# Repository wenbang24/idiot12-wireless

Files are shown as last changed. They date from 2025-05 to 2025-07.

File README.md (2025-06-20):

# idiot12-wireless
the idiot12, now in wireless form factor (see [https://github.com/wenbang24/idiot17](https://github.com/wenbang24/idiot17) and [https://github.com/wenbang24/idiot12](https://github.com/wenbang24/idiot12) for context)

a wireless split keyboard with every alpha key fitting on one layer with 12 keys
uses holyiot 18010 nRF52840 module, USB-C charging, and Kailh Choc switches

reduce your finger movement, and have your thumb and pinky free to do other things
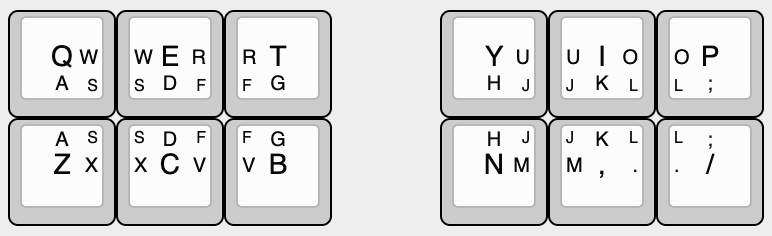
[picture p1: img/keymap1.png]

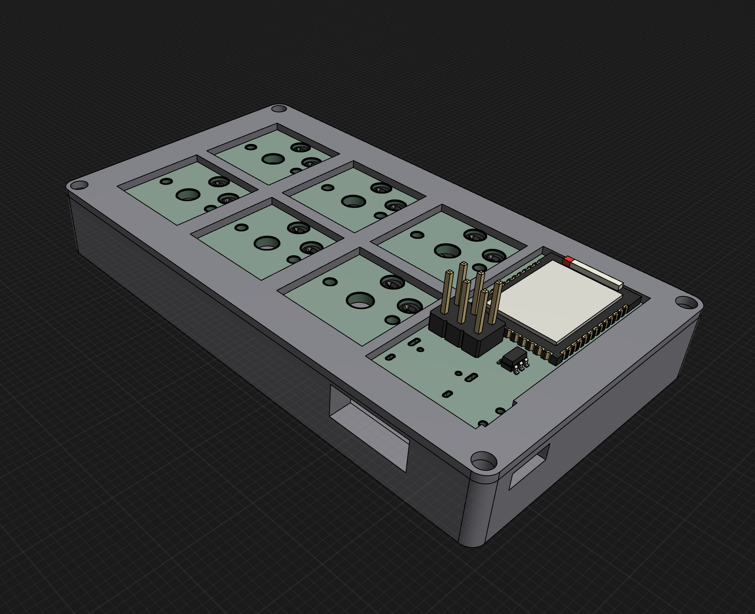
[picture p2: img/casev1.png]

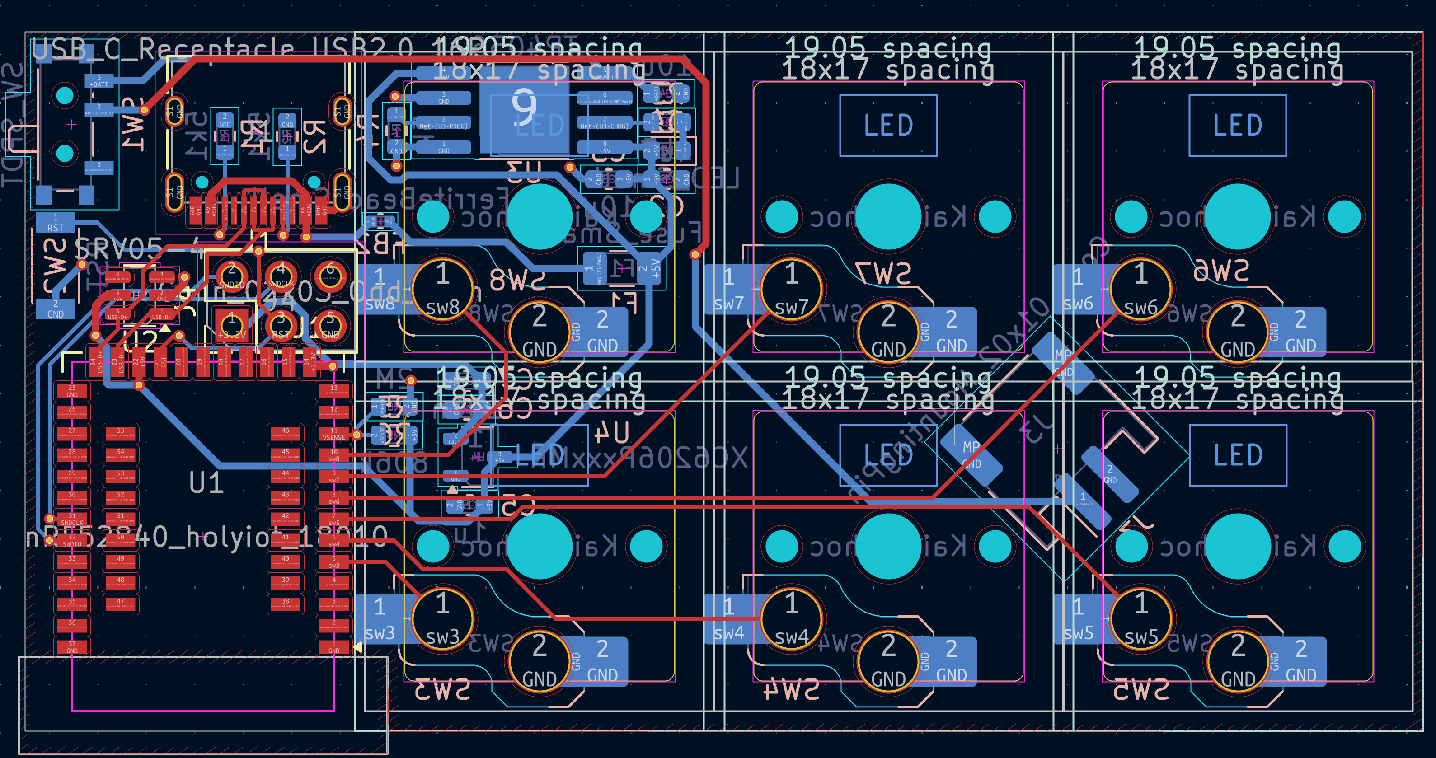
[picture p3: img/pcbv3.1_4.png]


# BOM
This is just for one side; double it for both sides.
|Designator |Footprint |Quantity|Value |LCSC Part #|
|---|---|---|---|---|
|C2 |0603 |1 |4u7 |C19666 |
|C3, C4 |0603 |2 |10u |C19702 |
|C5, C6 |0603 |2 |1u |C15849 |
|C7 |0603 |1 |100n |C14663 |
|D2 |0603 |1 |LED_Small |C2286 |
|F1 |1206 |1 |Fuse_Small |C151162 |
|FB2 |0402 |1 |FerriteBead_Small |C160976 |
|J1 |USB_C_Receptacle_HRO_TYPE-C-31-M-12 |1 |USB_C_Receptacle_USB2.0_16P|C165948 |
|J3 |JST_PH_S2B-PH-SM4-TB_1x02-1MP_P2.00mm_Horizontal|1 |Conn_01x02_MountingPin |C295747 |
|J4 |PinHeader_2x03_P2.54mm_Vertical |1 |Conn_02x03_Odd_Even |C5116479 |
|R1, R2 |0603 |2 |5k1 |C23186 |
|R3 |0603 |1 |1k5 |C22843 |
|R4 |0603 |1 |5k |C23186 |
|R5 |0603 |1 |806k |C403362 |
|R6 |0603 |1 |2M |C4077045 |
|SW1 |SW_SPDT_PCM12 |1 |SW_SPDT |C221841 |
|SW2 |TS-1088R-02526 |1 |RST |C720477 |
|SW3, SW4, SW5, SW6, SW7, SW8|SW_choc_v1_HS_CPG135001S30_1u |6 |Kailh_Choc | |
|U1 |nRF52840_holyiot_18010 |1 |nRF52840_holyiot_18010 | |
|U2 |SOT-23-6 |1 |SRV05-4 |C316033 |
|U3 |SOP-8-1EP_4.57x4.57mm_P1.27mm_EP4.57x4.45mm |1 |TP4056 |C16581 |
|U4 |SOT-23-3 |1 |XC6206PxxxMR |C5446 |

## Parts to source yourself:
- Holyiot 18010 e.g. [this](https://www.aliexpress.com/item/32868002366.html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)
- USB-C receptacle (TYPE-C-31-M-12) e.g. [this](https://www.aliexpress.com/item/1005003285152827.html)
- SRV-05 e.g. [this](https://www.aliexpress.com/item/1005007499115687.html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)
- 2.54mm 2x3 pin header e.g. [this](https://www.aliexpress.com/item/4000303366348.html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)
- 3.7V LiPo battery (around 120mAh) with 2mm JST PH header e.g. [this](https://core-electronics.com.au/lipo-polymer-lithium-ion-battery-120mah.html)
- 4x M3 10mm screws e.g. [this](https://www.bunnings.com.au/pinnacle-m3-x-10mm-zinc-plated-round-head-bolts-and-nuts-20-pack_p0247262)
- 6x Kailh Choc switches e.g. [this](https://www.aliexpress.com/item/1005005883472162.html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)
- 6x Kailh Choc keycaps e.g. [this](https://www.aliexpress.com/item/32949747794.html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)

PCBA cost: $34.56
**Cost**: $84.29 USD (excluding shipping)

Estimated total: $100 USD

(prices converted from AUD to USD, accurate as of 2025-06-16)

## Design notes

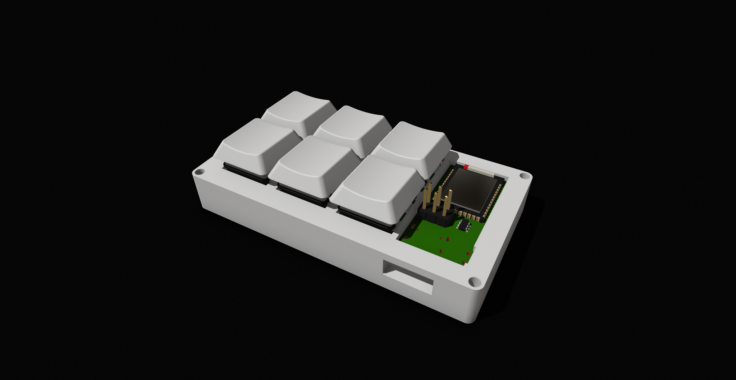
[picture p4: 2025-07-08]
img/Untitled.png

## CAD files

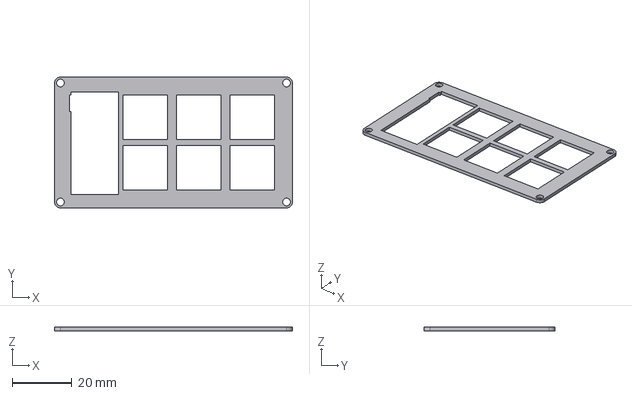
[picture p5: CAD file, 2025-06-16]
case/plate.step
80.0 x 44.0 x 1.20 mm

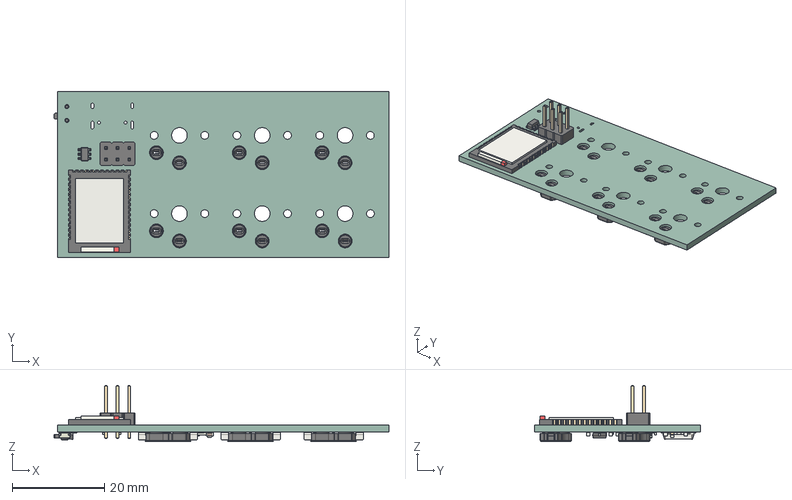
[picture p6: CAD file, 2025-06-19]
pcb/pcb.step
72.8 x 36.1 x 12.2 mm
SOT-23-6
PinHeader_2x03_P2.54mm_Vertical
holyiot_18010_nRF52840
pin x 12
socket x 6
R_0603_1608Metric x 6
Fuse_1206_3216Metric
SW_SPST_B3U-1000P
C_0603_1608Metric x 6
LED_0603_1608Metric
SOT-23-3
SW_SPDT_PCM12
C_0402_1005Metric
pcb_PCB

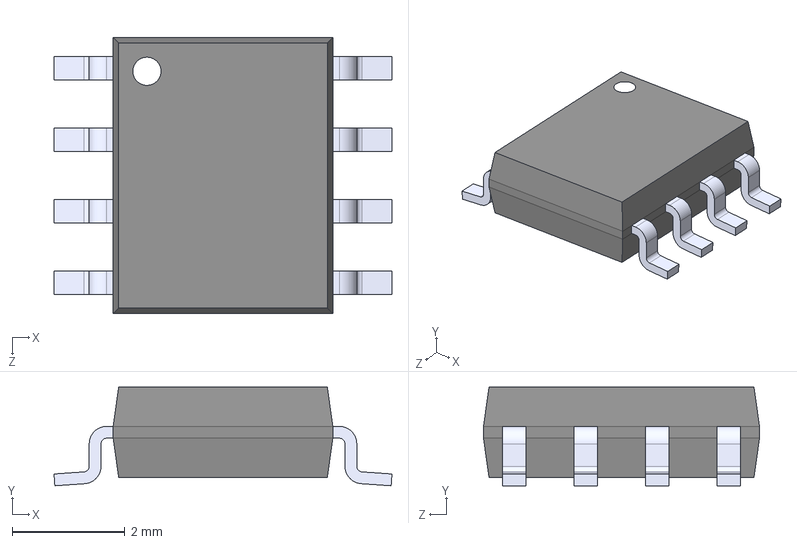
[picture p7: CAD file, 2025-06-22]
pcb/TP4056/TP4056.step
6.00 x 1.75 x 4.90 mm

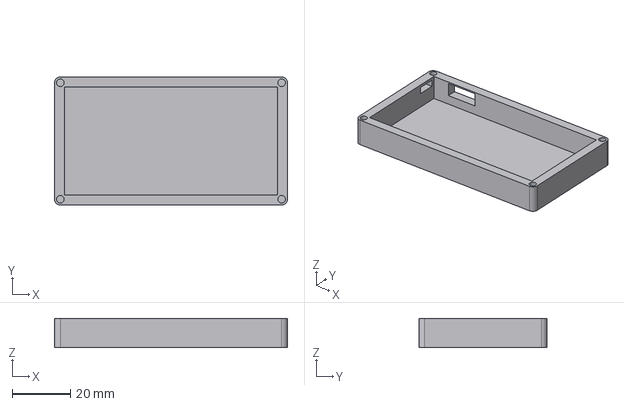
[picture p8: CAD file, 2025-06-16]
case/case.step
80.0 x 44.0 x 10.0 mm

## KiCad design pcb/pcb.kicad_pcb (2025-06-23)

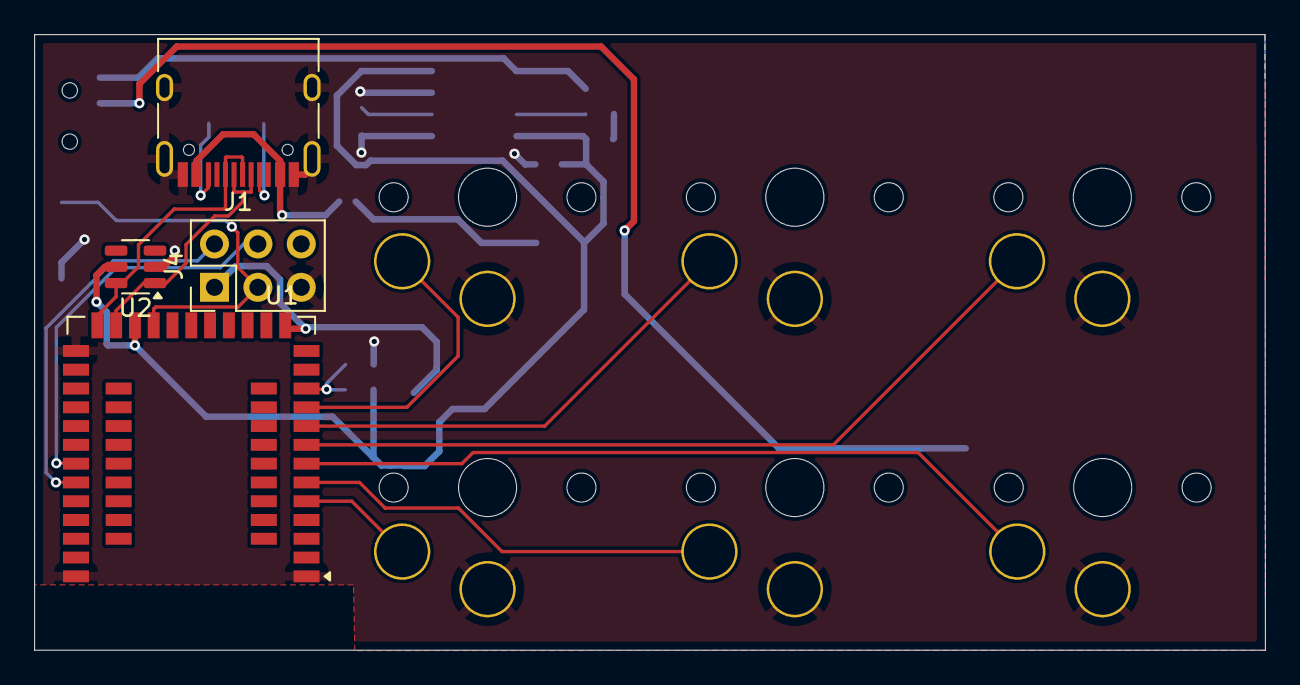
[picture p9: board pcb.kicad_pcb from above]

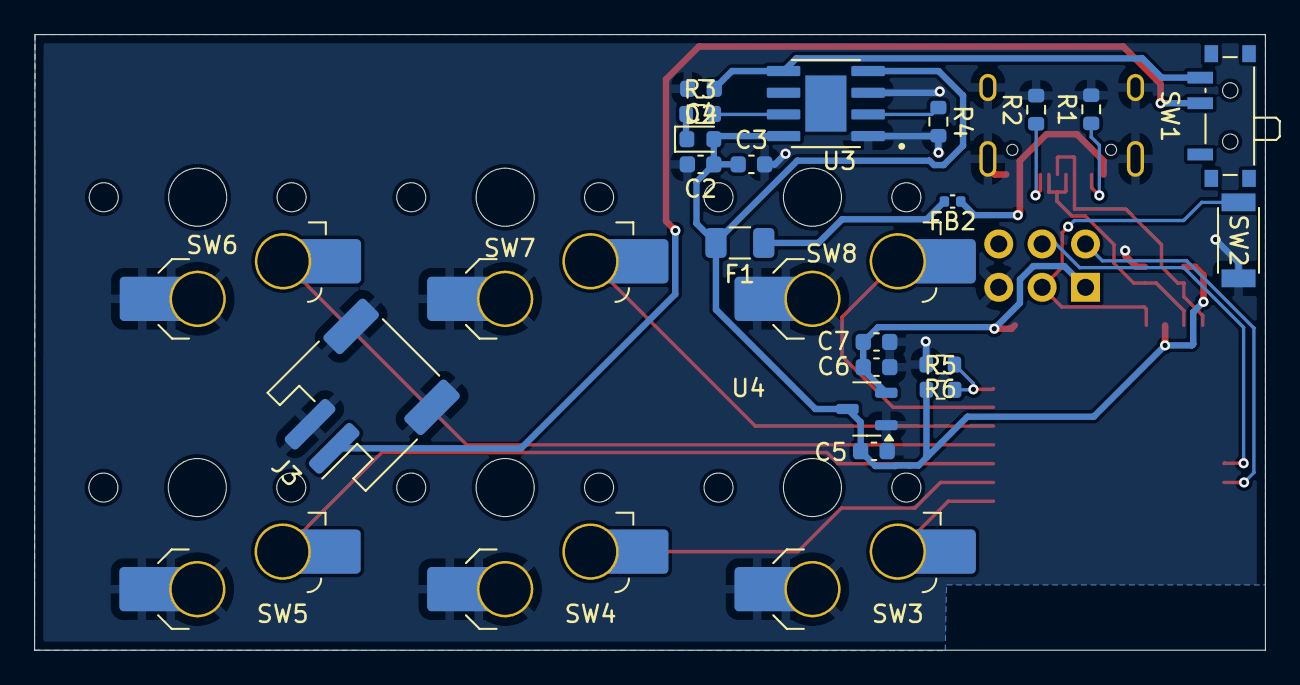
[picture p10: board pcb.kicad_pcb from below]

Board: 2 copper layers, 72.1 x 36.1 mm, 30 parts (26 on the bottom side), 24 nets.

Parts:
C2: 4u7; C_0603_1608Metric
C3, C4: 10u; C_0603_1608Metric
C5, C6: 1u; C_0603_1608Metric
C7: 100n; C_0603_1608Metric
D2: LED_Small; LED_0603_1608Metric
F1: Fuse_Small; Fuse_1206_3216Metric
FB2: FerriteBead_Small; C_0402_1005Metric
J1: USB_C_Receptacle_USB2.0_16P; USB_C_Receptacle_HRO_TYPE-C-31-M-12
J3: Conn_01x02_MountingPin; JST_PH_S2B-PH-SM4-TB_1x02-1MP_P2.00mm_Horizontal
J4: Conn_02x03_Odd_Even; PinHeader_2x03_P2.54mm_Vertical
R1, R2: 5k1; R_0603_1608Metric
R3: 1k5; R_0603_1608Metric
R4: 5k; R_0603_1608Metric
R5: 806k; R_0603_1608Metric
R6: 2M; R_0603_1608Metric
SW1: SW_SPDT; SW_SPDT_PCM12
SW2: RST; TS-1088R-02526
SW3, SW4, SW5, SW6, SW7, SW8: Kailh_Choc; SW_choc_v1_HS_CPG135001S30_1u
U1: nRF52840_holyiot_18010
U2: SRV05-4; SOT-23-6
U3: TP4056; SOP127P600X175-9N
U4: XC6206PxxxMR; SOT-23-3

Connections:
+3.3V: C6.1, C7.1, J4.1, U1.14 (VDD_nRF), U4.2 (VO)
+5V: C2.1, C3.1, C5.1, D2.2 (A), F1.2, R5.1, U1.22 (VBUS), U2.5 (VP), U3.4 (VCC), U3.8 (CE), U4.3 (VI)
+BATT: C4.1, SW1.3 (C), U3.5 (BAT)
/RST: J4.3, SW2.1, U1.21 (P0.18-RESET)
/SWDCLK: J4.4, U1.31 (SWDCLK)
/SWDIO: J4.2, U1.32 (SWDIO)
/USB-D+: J1.A6 (D+), J1.B6 (D+), U1.24 (D+), U2.6 (IO4)
/USB-D-: J1.A7 (D-), J1.B7 (D-), U1.23 (D-), U2.1 (IO1)
/VSENSE: R5.2, R6.1, U1.11 (P0.31-LF-A)
/sw3: SW3.1, U1.5 (P1.15-LF)
/sw4: SW4.1, U1.6 (P0.03-LF-A)
/sw5: SW5.1, U1.7 (P0.02-LF-A)
/sw6: SW6.1, U1.8 (P0.28-LF-A)
/sw7: SW7.1, U1.9 (P0.29-LF-A)
/sw8: SW8.1, U1.10 (P0.30-LF-A)
GND: C2.2, C3.2, C4.2, C5.2, C6.2, C7.2, J1.A1 (GND), J1.A12 (GND), J1.B1 (GND), J1.B12 (GND), J1.S1 (SHIELD), J3.2, J3.MP (MountPin), J4.5, R1.2, R2.2, R4.2, R6.2, SW2.2, SW3.2, SW4.2, SW5.2, SW6.2, SW7.2, SW8.2, U1.1 (GND), U1.25 (GND), U1.37 (GND), U2.2 (VN), U3.1 (TEMP), U3.3 (GND), U4.1 (GND)
unnamed: D2.1 (K), R3.1
unnamed: F1.1, FB2.2
unnamed: J1.A5 (CC1), R2.1
unnamed: J1.B5 (CC2), R1.1
unnamed: J3.1, SW1.2 (B)
unnamed: R3.2, U3.7 (CHRG)
unnamed: R4.1, U3.2 (PROG)
VBUS: FB2.1, J1.A4 (VBUS), J1.A9 (VBUS), J1.B4 (VBUS), J1.B9 (VBUS)

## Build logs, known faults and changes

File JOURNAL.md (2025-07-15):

---
title: "Idiot12 Wireless Edition"
author: "Ben Wang"
description: "12 keys, one alpha layer - now in wireless form factor!"
created_at: "2025-05-22"
---

total time (so far): 32 hrs

# Journal of Changes
## 22 May 2025 - Keymap
Initial draft of the alpha layer (note: will probably not use qwerty because most frequently used letters should only require one keypress)


Explanation:
- Press Q for Q
- Press Q and Z for A
- Press Q, E, Z, and C for S

(a bit of a weird system but its kinda cool)

Time spent: 30 mins

## 24 May 2025 - Schematic
1st draft of the schematic - hoping it doesn't blow up :)

Time spent: 3 hrs
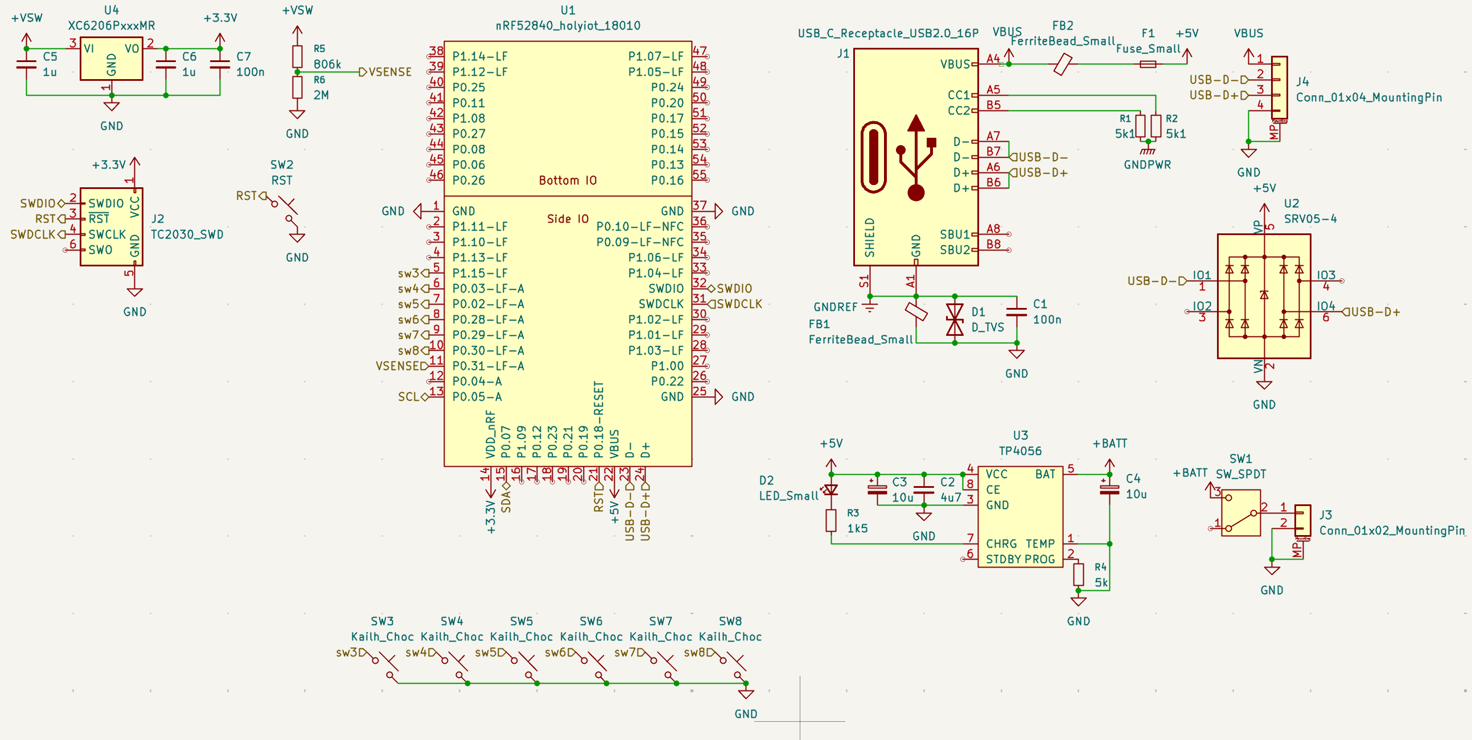
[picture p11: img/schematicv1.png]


2nd draft - removed some unnecessary voltage sensing circuitry

Time spent: 1 hr
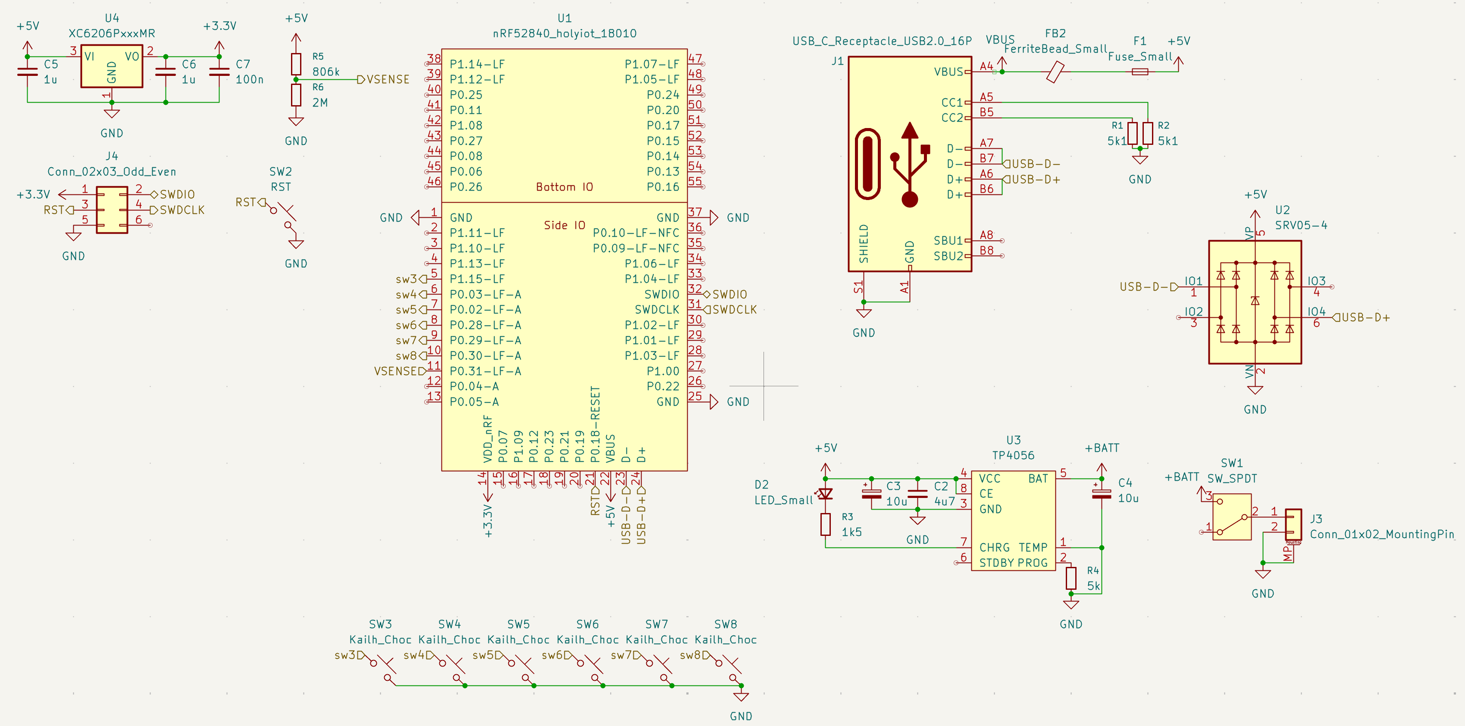
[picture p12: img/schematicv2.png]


## 29 May 2025 - PCB Routing
@koeg on Slack has told me that my schematic is ok :)

Removed the really expensive debug connector and replaced it with a normal 6 pin ICSP header

Also routed the PCB

Time spent: 4.5 hrs
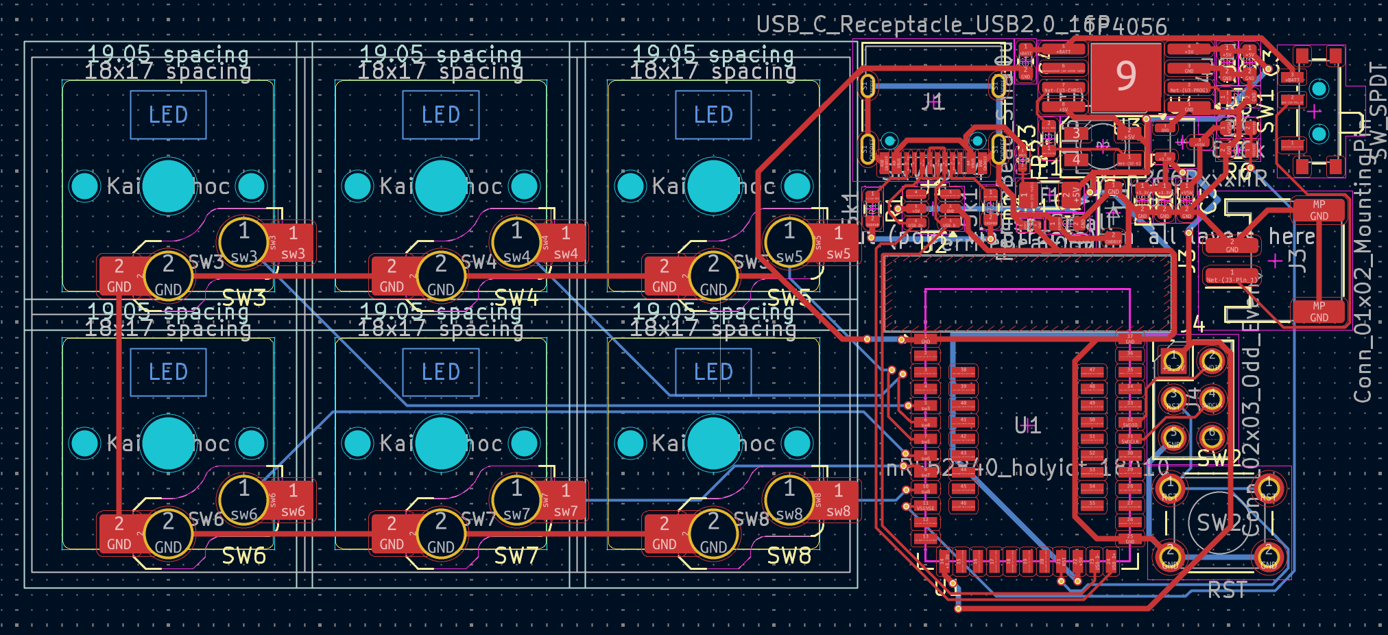
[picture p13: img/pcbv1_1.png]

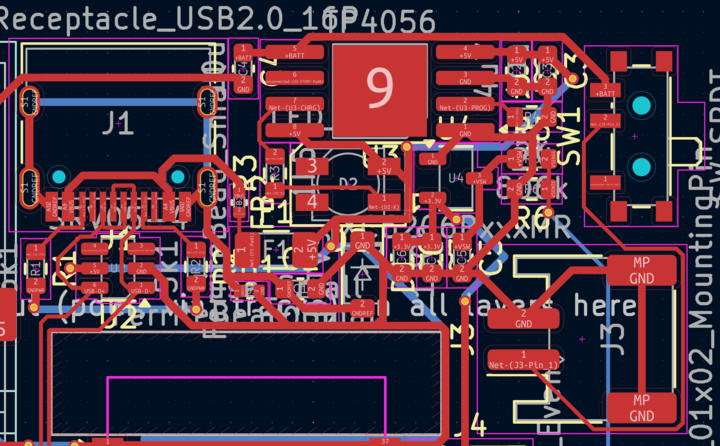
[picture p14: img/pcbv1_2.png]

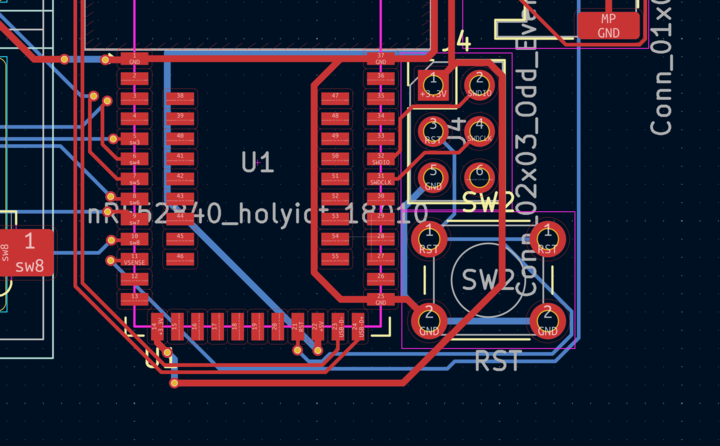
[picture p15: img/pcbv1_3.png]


## 30 May 2025 - PCB Review, starting v2
@koeg has reviewed my PCB (tysm), added a ground and 5V plane, so restarted routing

Time spent: 3 hrs

## 31 May 2025 - PCB Review, v2
A new day, a new PCB iteration

Finished 2nd draft of PCB, awaiting review

Time spent: 3 hrs
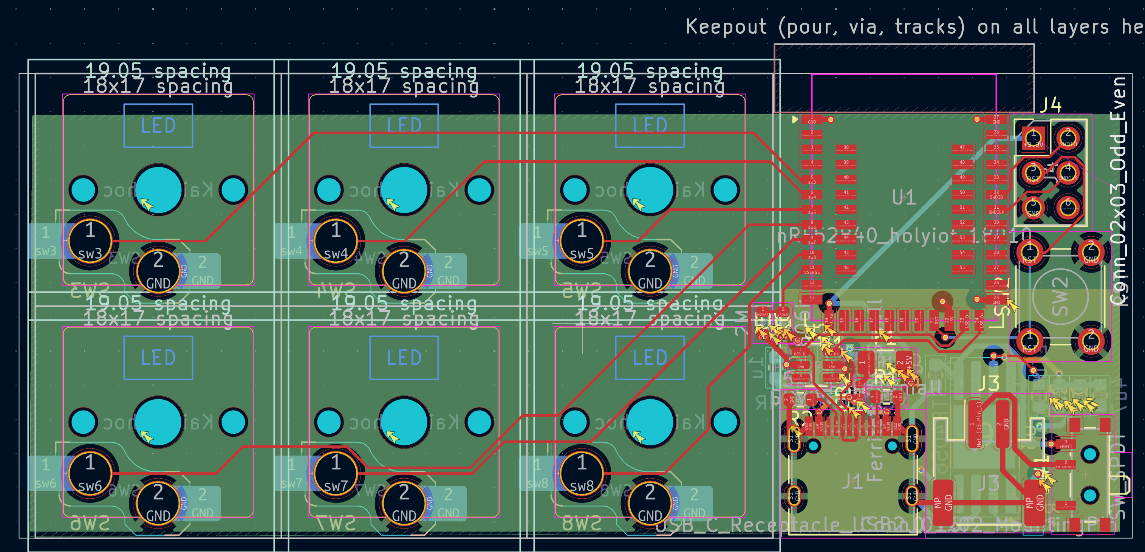
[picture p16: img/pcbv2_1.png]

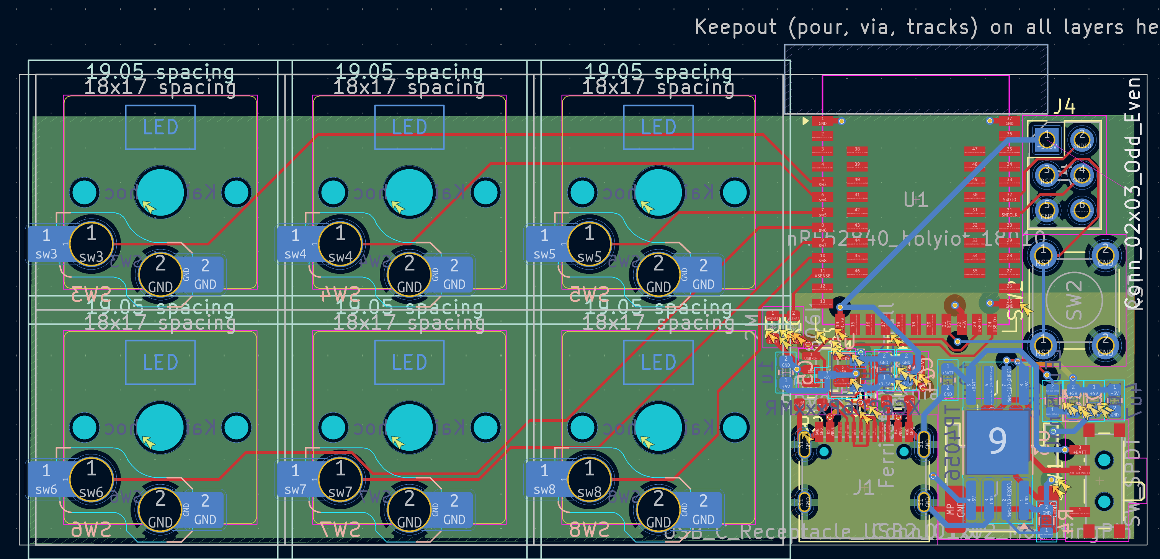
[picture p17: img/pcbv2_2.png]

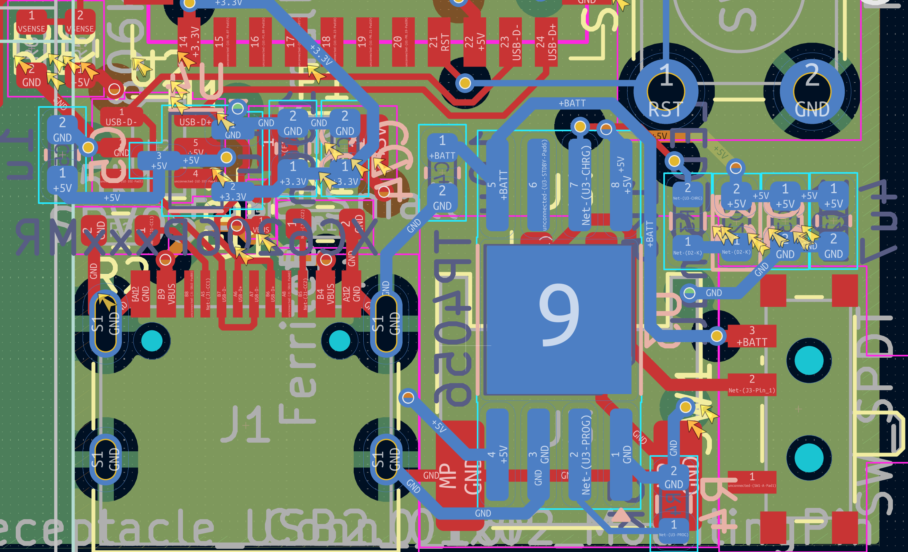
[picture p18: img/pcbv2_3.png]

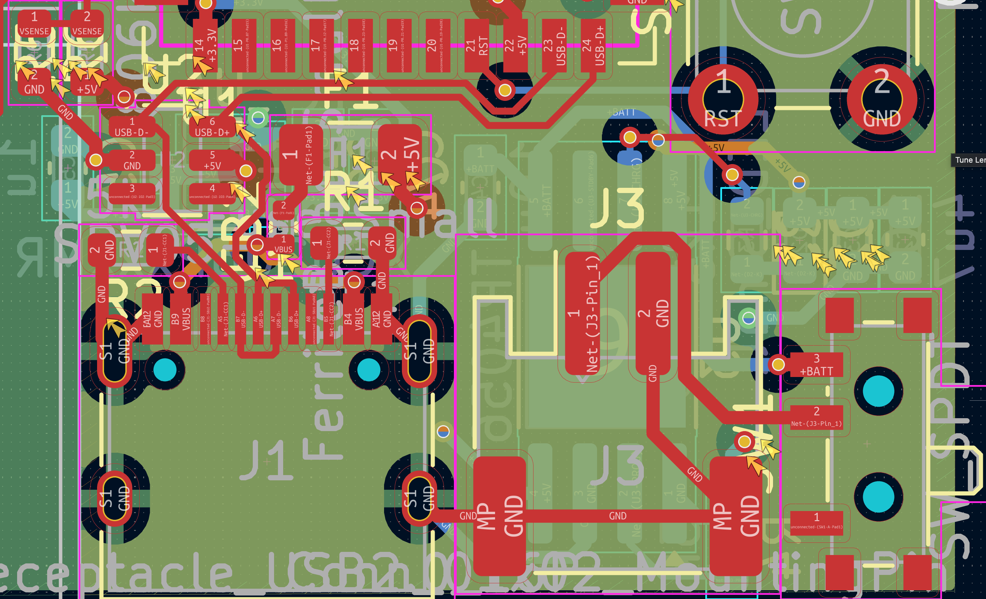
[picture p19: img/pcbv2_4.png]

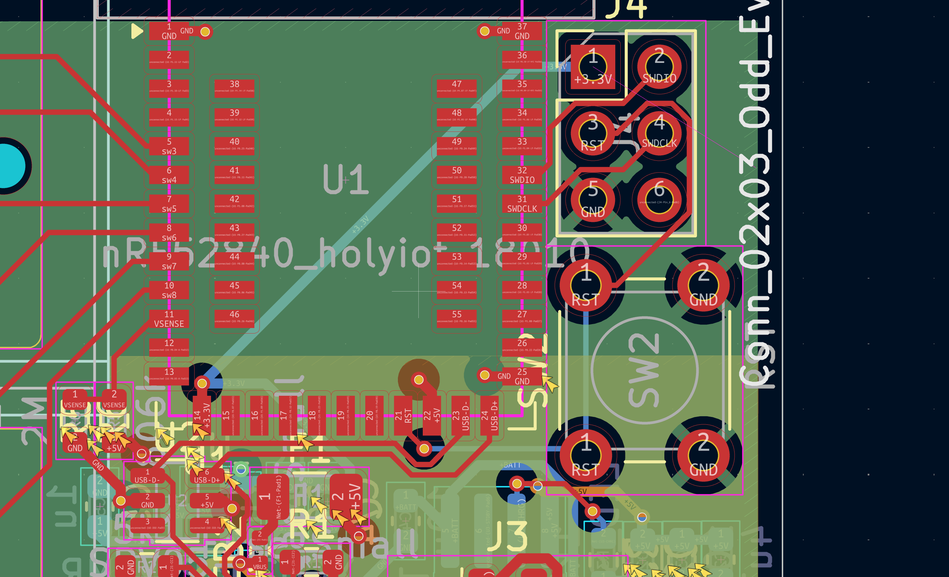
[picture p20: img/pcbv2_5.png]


## 1 June - 13 June 2025 - Exams (not an actual journal entry)
:|

## 13 June 2025 - PCB Review, v3
Finally back from exams, and I have a new PCB revision! Now using 2 layers instead of 4, which is much cheaper :). Also realised that I could put components behind the switches, so I did that. It is much smaller now.

Time spent: 4 hrs
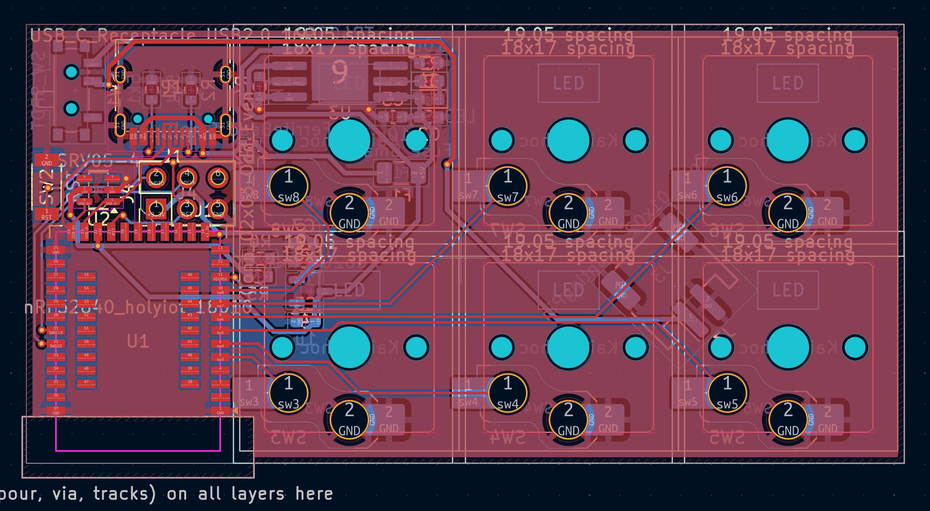
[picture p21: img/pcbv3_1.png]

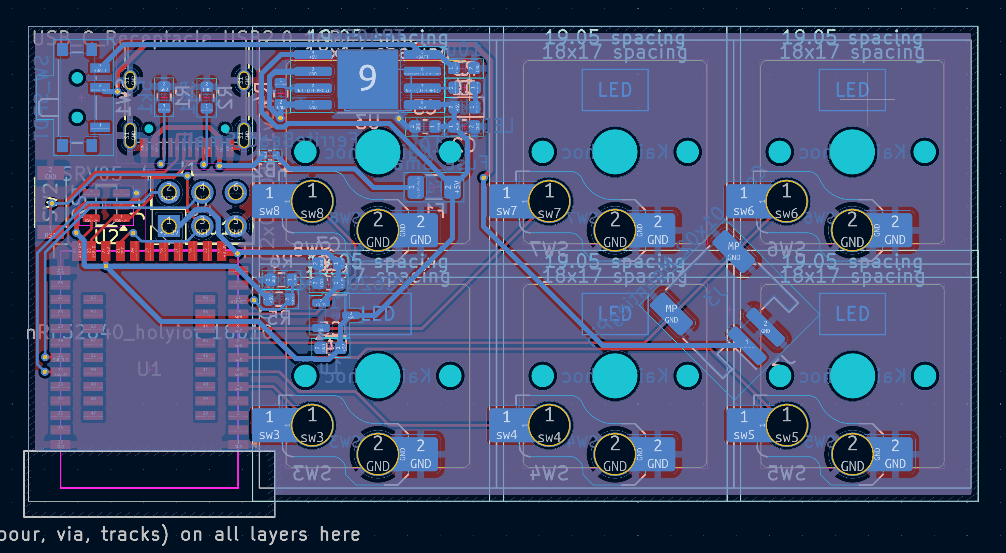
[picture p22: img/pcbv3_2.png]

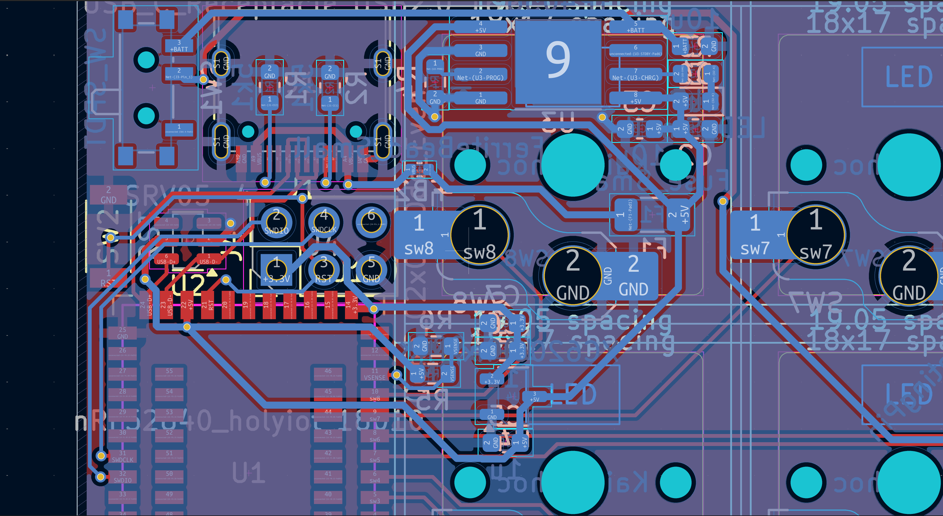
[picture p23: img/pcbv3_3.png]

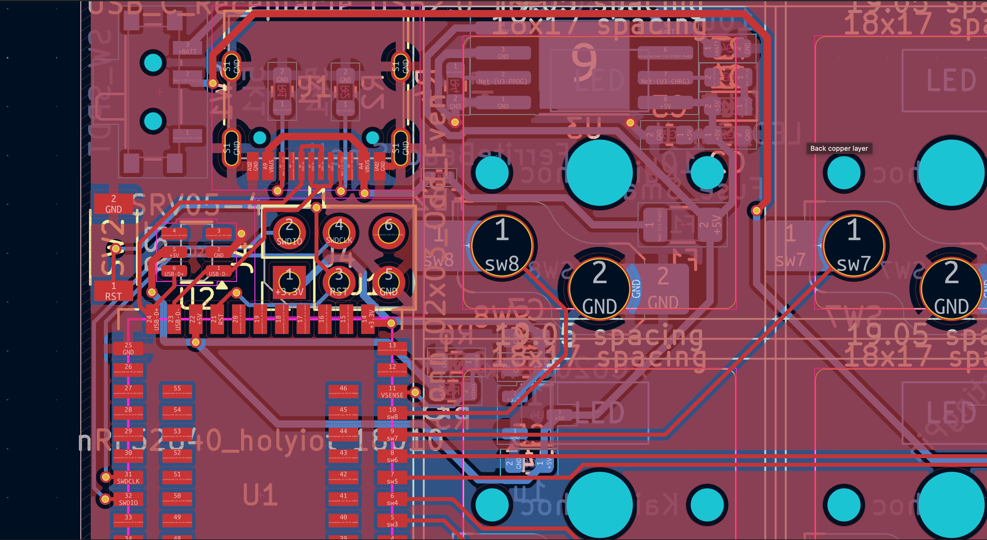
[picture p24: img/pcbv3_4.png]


## 16 June 2025 - PCB Review, v3.1, Case, BOM part 1
A few minor changes with routing, modelled the case, and started researching for parts to use in the BOM

Time spent: 5 hrs
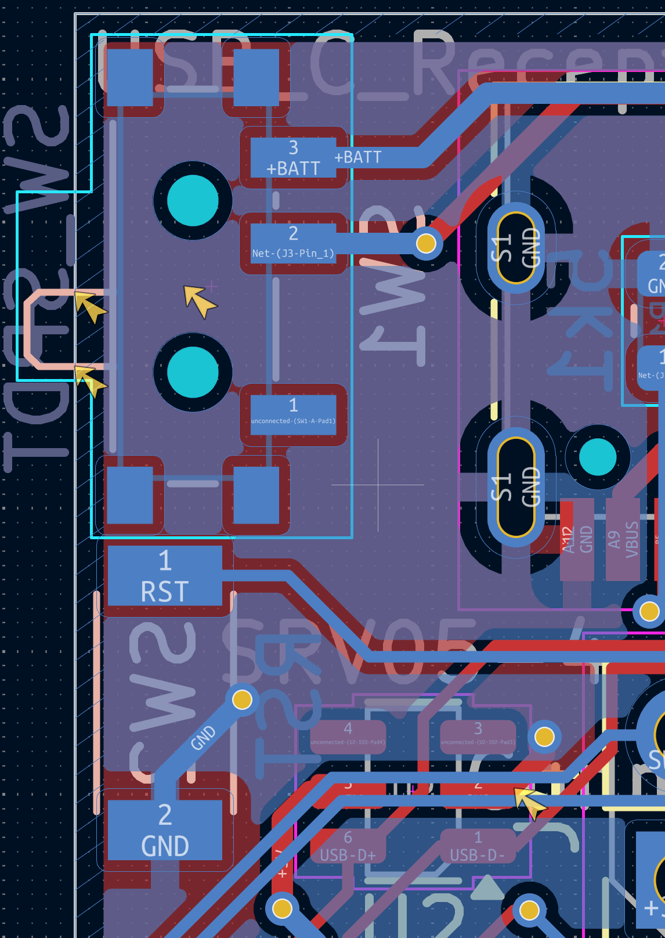
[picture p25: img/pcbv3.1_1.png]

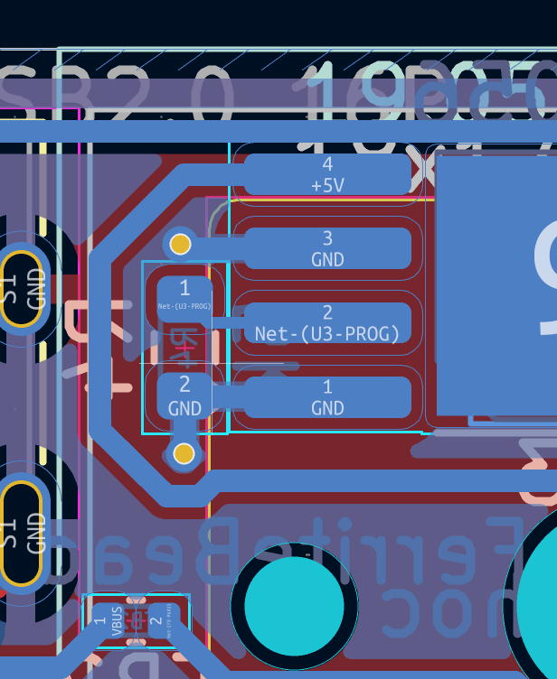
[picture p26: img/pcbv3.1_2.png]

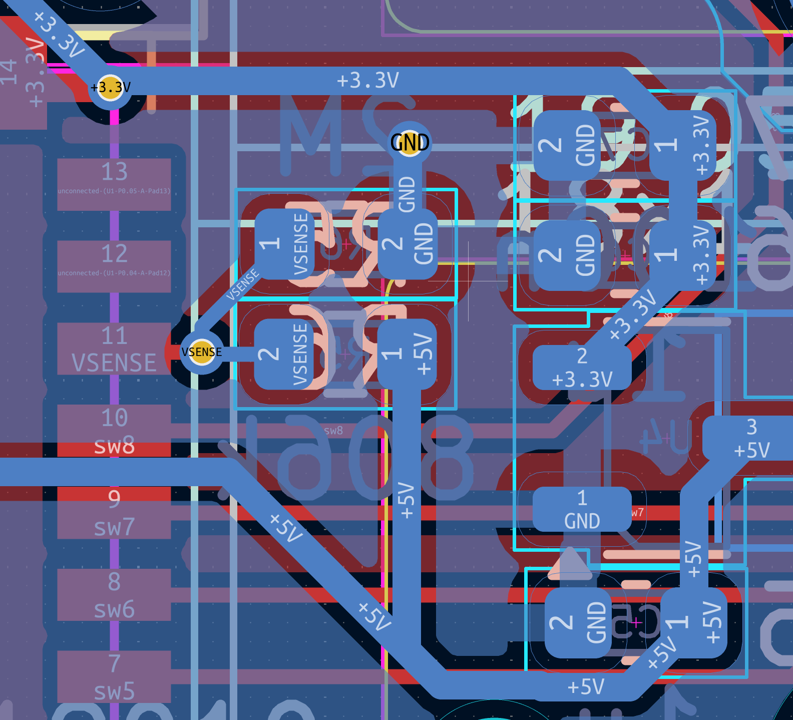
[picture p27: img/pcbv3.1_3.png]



## 17 June 2025 - BOM part 2
Added the rest of the BOM, and also added some links to parts that I will need to source myself
Also calculated the cost of the BOM, which is around $55 USD (excluding shipping)
(it took way too long to find the JST PH connectors)

Time spent: 3 hrs

## 19 June 2025 - Firmware
Made firmware for the keyboard using ZMK.

Honestly I have no idea whether it works or not, but I guess I will find out when I get the parts.

Time spent: 5 hrs

## 7 July 2025 - PCBA
PCB is here!

Soldered on the NRF52840 module, SRV-05, the USB-C port, and the choc sockets. Figuring out the orentation of the SRV-05 was a bit tricky, but I think (hope) I got it right (drag soldering is a lot easier than I thought it would be).

(also i only did one half)




Time spent: 3 hrs

## 8 July 2025 - Firmware
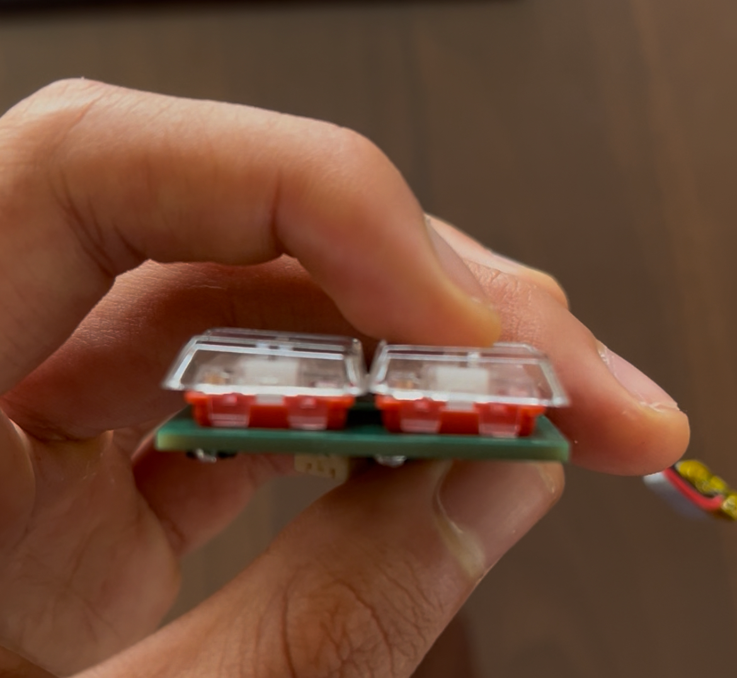
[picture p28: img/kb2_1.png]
The keycaps I ordered are a bit long and actuating the adjacent switch, so I had to sand some off with the Dremel. 

Printed the plate.

Spent ages figuring out how to flash the bootloader.



Time spent: 5 hrs

## 12 July 2025 - Firmware again
NONE OF IT WORKS AAAAAAAAAA
(it's not showing up when i press reset twice)

Time spent: 4 hrs

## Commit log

2025-05-23 add submodules
    [pcb.kicad_pcb, pcb.kicad_sch]
2025-05-23 basic usb schematics
    [pcb.kicad_sch]
2025-05-24 schematic 1st draft
    [pcb.kicad_sch]
2025-05-24 remove unecessary battery voltage sensing circuitry
    [pcb.kicad_sch]
2025-05-25 finish footprint assignment
    [pcb.kicad_pcb, pcb.kicad_sch]
2025-05-26 routing is hard
    [pcb.kicad_pcb, pcb.kicad_sch]
2025-05-29 finish routing first draft
    [pcb.kicad_pcb]
2025-05-29 pcb routing
2025-05-30 one one gnd net, also get rid of some components
    [pcb.kicad_pcb, pcb.kicad_sch]
2025-05-30 continue routing
    [pcb.kicad_pcb]
2025-05-30 finish routing 2nd draft
    [pcb.kicad_pcb, pcb.kicad_sch]
2025-06-03 update ground and 5v pours to cover the whole board
    [pcb.kicad_pcb]
2025-06-09 update gnd pour
    [pcb.kicad_pcb]
2025-06-13 pcb v3 - 2 layers again
    [pcb.kicad_pcb, pcb.kicad_sch]
2025-06-15 small changes to pcb, also did some bom
    [pcb.kicad_pcb, pcb.kicad_sch, pcb.step]
2025-06-16 bom and gerbers
    [pcb.kicad_pcb, pcb.kicad_sch]
2025-06-16 a few more images
    [bom.csv]
2025-06-19 firmware in zmk (wow that was hard)
    [pcb.kicad_pcb, pcb.step]
2025-06-20 update prod files
    [bom.csv, positions.csv]
2025-06-22 update tp4056 footprint
    [TP4056.step, bom.csv, pcb.kicad_pcb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]
2025-06-23 small changes to bom
    [pcb.kicad_pcb]
2025-07-08 assembly 1
